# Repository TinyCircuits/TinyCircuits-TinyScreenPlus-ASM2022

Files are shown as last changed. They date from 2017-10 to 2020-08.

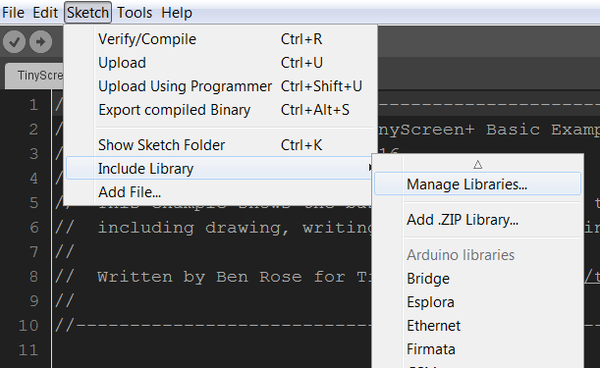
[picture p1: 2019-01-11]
images/tutorial_images/ASM2022-Tutorial-Image-07.png

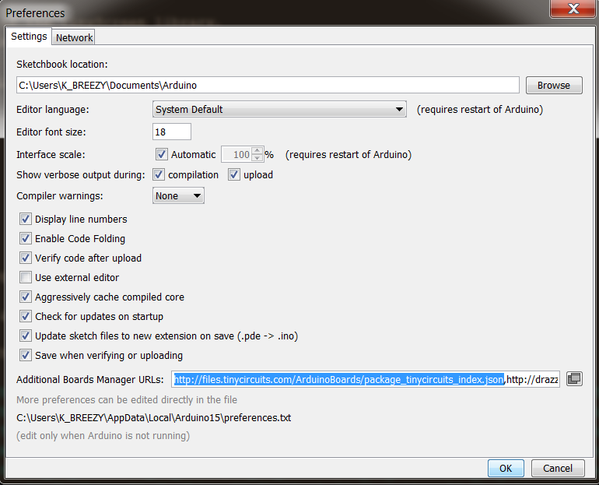
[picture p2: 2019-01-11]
images/tutorial_images/ASM2022-Tutorial-Image-03.png

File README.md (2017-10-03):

# TinyCircuits TinyScreen+ Processor Board
# ASM2022 Rev4

These are the design files for the TinyCircuits ASM2022 Rev 4 PCB.  This is a Tiny processor board that use an Ateml SAMD21 microcontroller and OLED has stackable TinyShield support.  

Format is in Cadsoft Eagle format - Eagle version 6.2 was used for the original design.

#License:

Design by TinyCircuits.
All design files are released under the Creative Commons Attribution Share-Alike 3.0 License, see the following link for details: http://creativecommons.org/licenses/by-sa/3.0

All text above must be included in any redistribution or derived design

This project uses designs and concepts developed as part of the Arduino project and the LilyPad project.  The TinyCircuits design files themselves (schematics, PCB and libraries) are not directly derived from these works' design files and have been created new, however the concepts and basic architecture behind the TinyDuino and TinyLily products are derived and we thank the hard work of the organizations below for their contributions to open-source hardware:
  
Original Arduino Uno Design by Team Arduino

LilyPad Arduino Design by Leah Buechley and Sparkfun Electronics

Please support the open-source hardware community

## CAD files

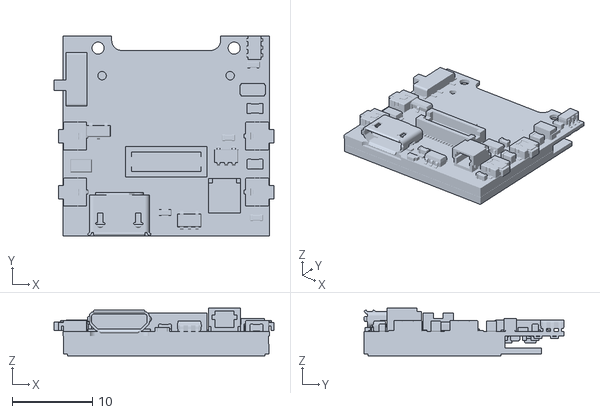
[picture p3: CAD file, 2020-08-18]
cad/TinyScreenPlus_ASM2022_REV4-STL.stl
27.5 x 25.0 x 5.94

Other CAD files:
cad/TinyScreenPlus_ASM2022_REV4-DETAILED_DRAWING-DXF.dxf

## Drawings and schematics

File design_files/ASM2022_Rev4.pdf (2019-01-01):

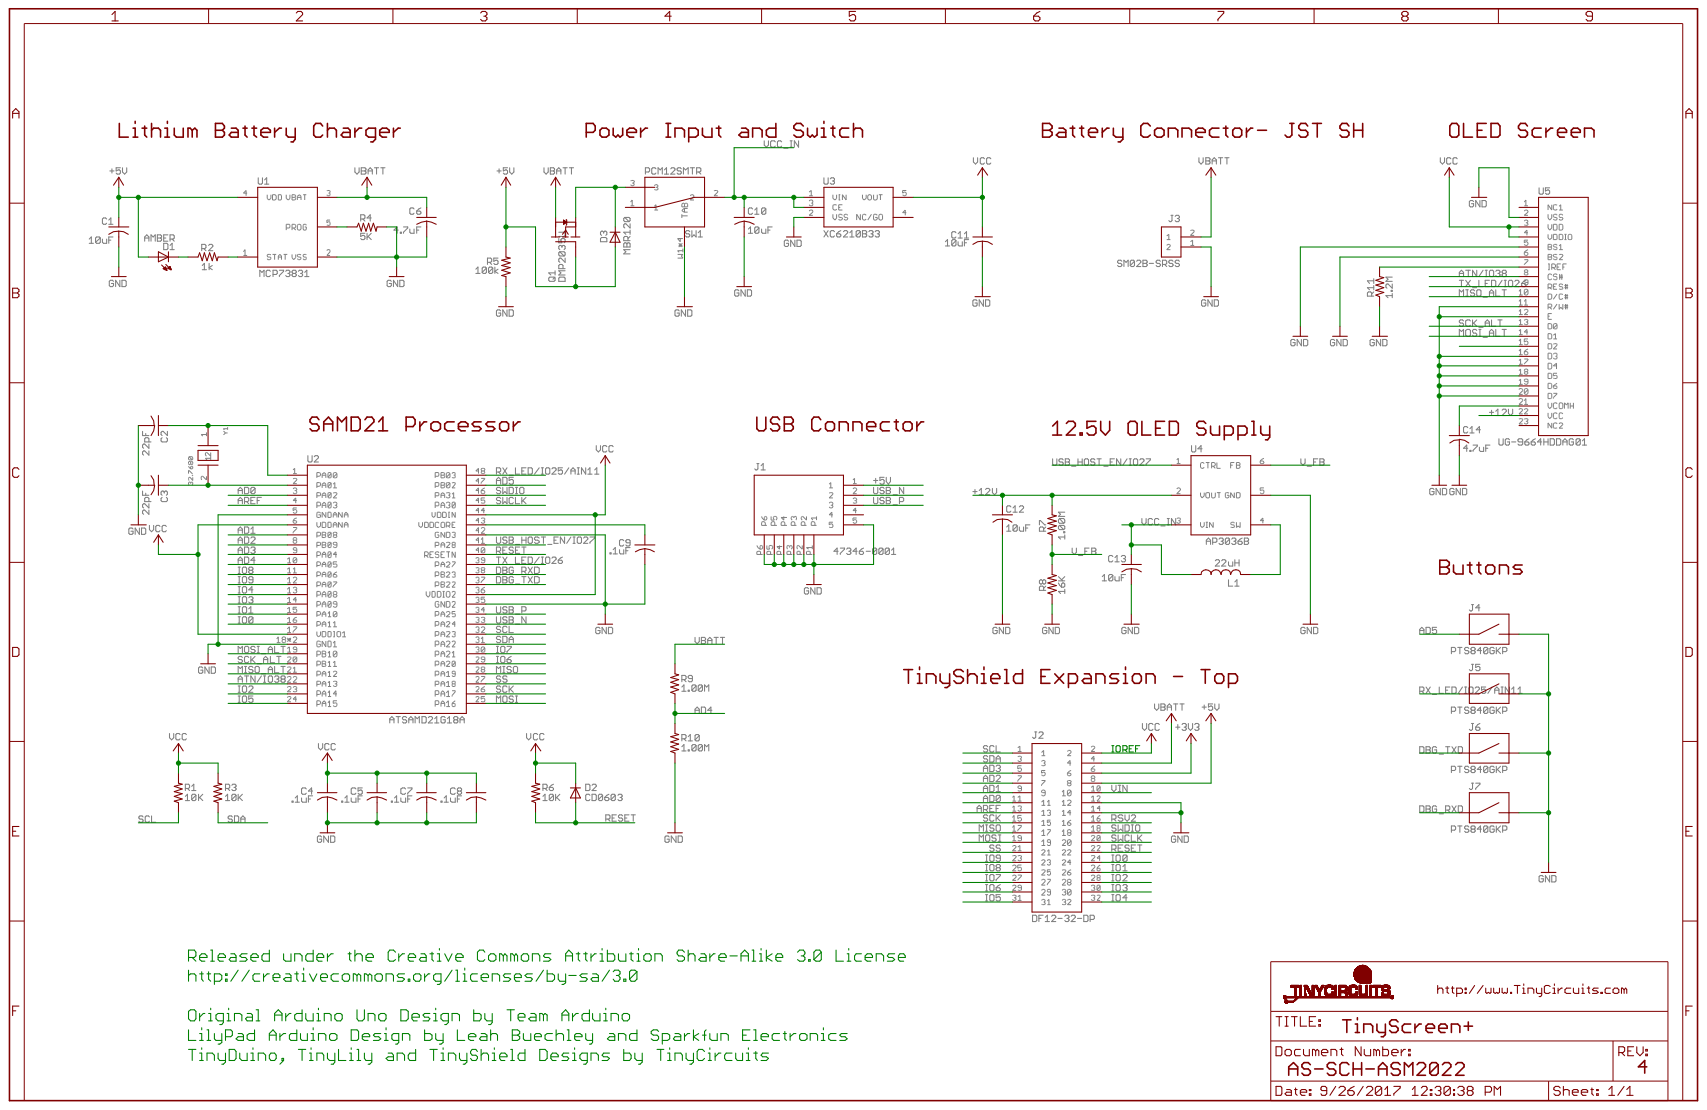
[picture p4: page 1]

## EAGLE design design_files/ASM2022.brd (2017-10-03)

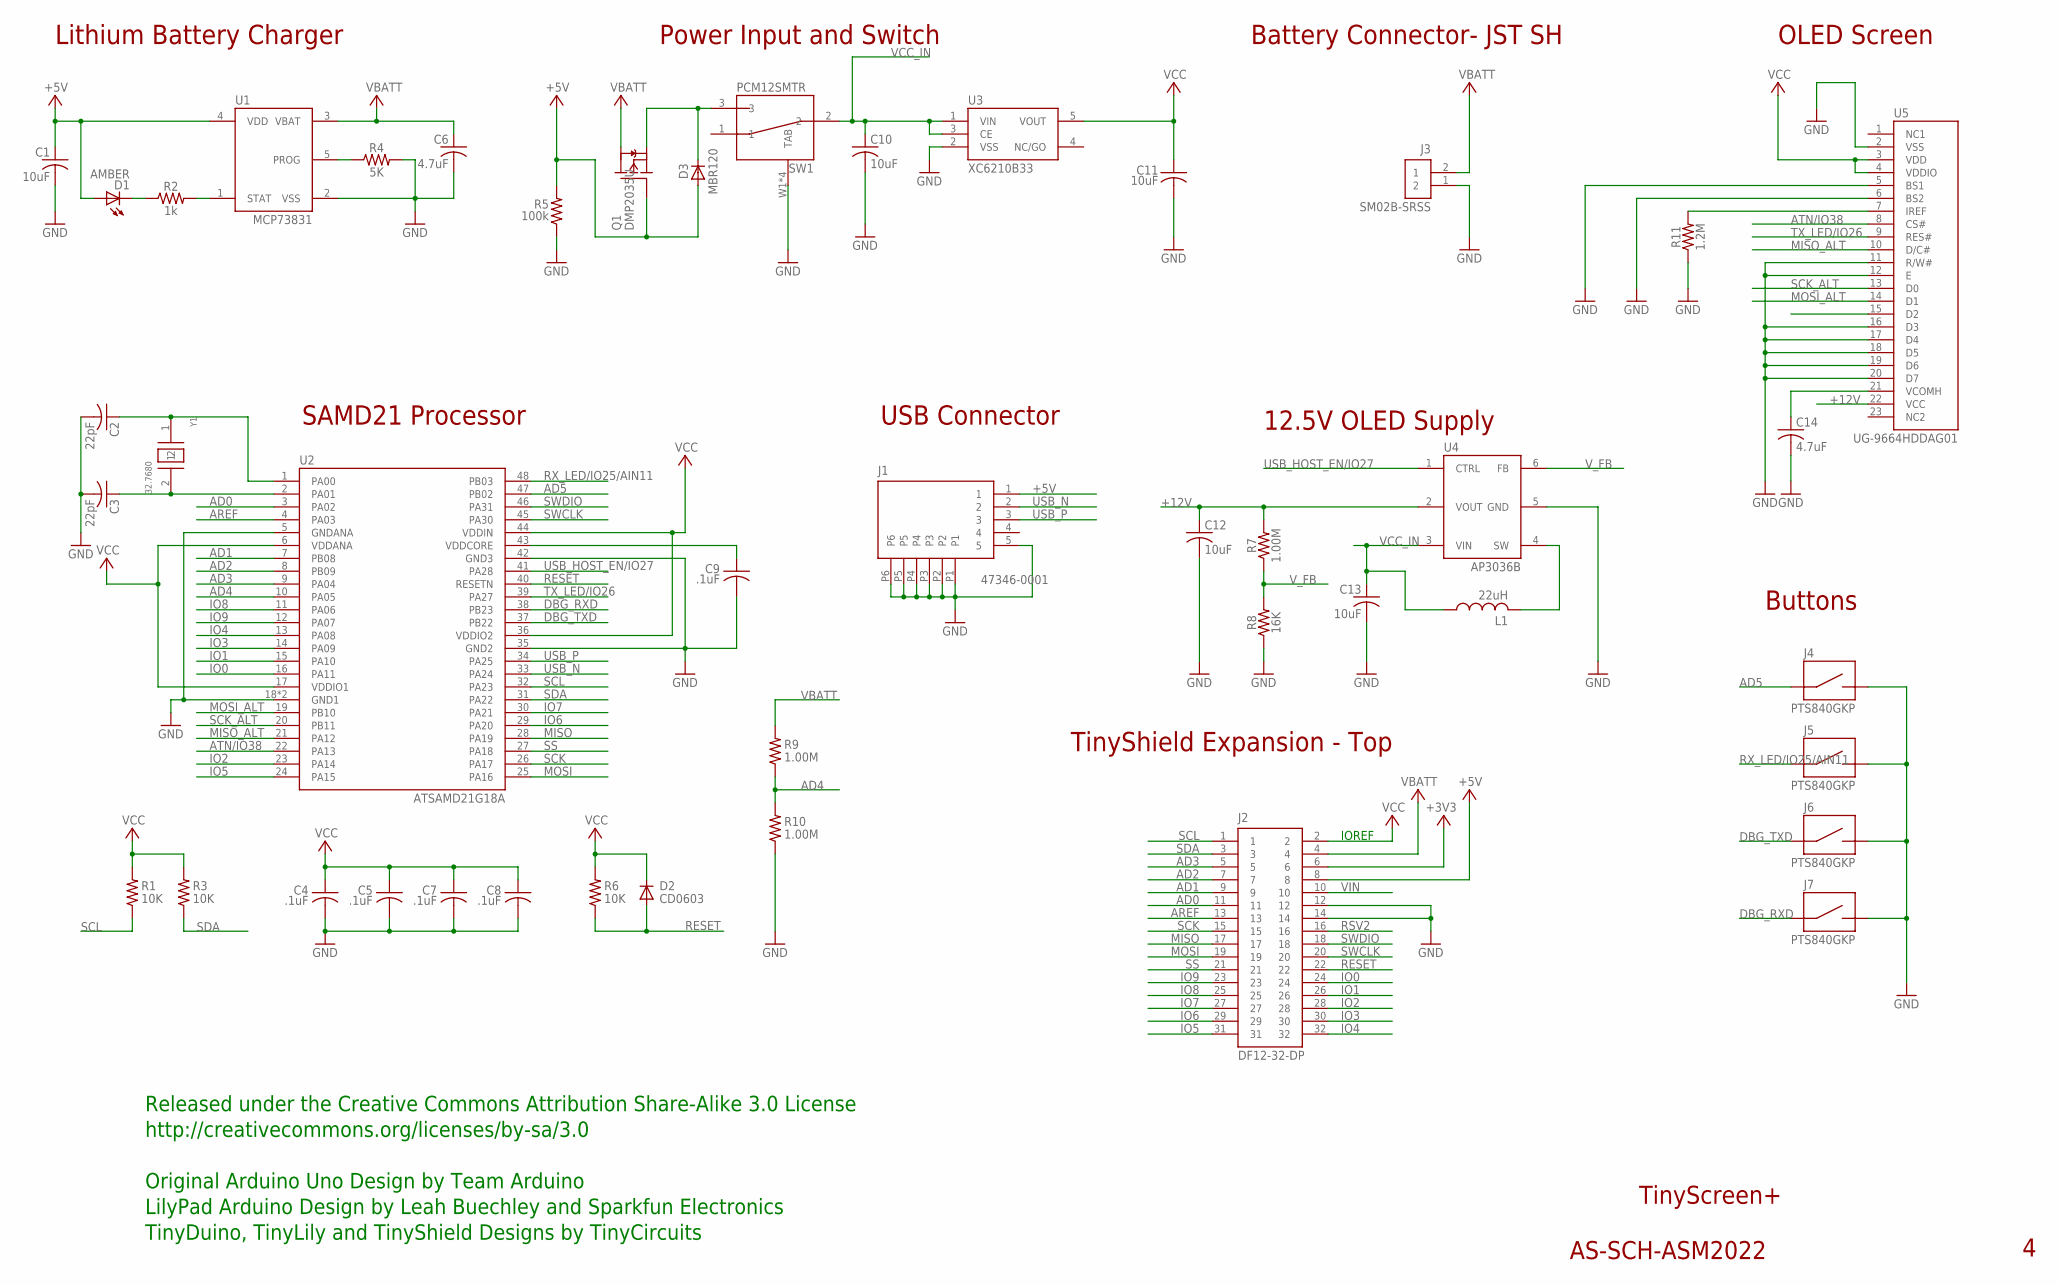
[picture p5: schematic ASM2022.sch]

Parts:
C1, C11, C13: 10uF; C0603; PARTNO AS-ITM-00002
C2, C3: 22pF; C0402; PARTNO AS-ITM-00211
C4, C5, C7, C8, C9: .1uF; C0402; PARTNO AS-ITM-00008
C6: 4.7uF; C0603; PARTNO AS-ITM-00088
C10, C12: 10uF; C0805; PARTNO AS-ITM-00045
C14: 4.7uF; 1206_CAP_TANT; PARTNO AS-ITM-00232
D1: AMBER; LNJ_LED; PARTNO AS-ITM-00026
D2: CD0603; 0603; PARTNO AS-ITM-00009
D3: MBR120; SOD-123FL
J1: 47346-0001; MICRO_USB
J2: DF12-32-DP; PARTNO AS-ITM-00015
J3: SM02B-SRSS; JST_SH_2X1
J4, J5, J6, J7: PTS840GKP; PARTNO AS-ITM-00236
L1: 22uH; R0805
Q1: DMP2035U; SOT23
R1, R3, R6: 10K; 0402; PARTNO AS-ITM-00032
R2: 1k; 0402; PARTNO AS-ITM-00003
R4: 5K; 0402
R5: 100k; 0402; PARTNO AS-ITM-00004
R7, R9, R10: 1.00M; 0402; PARTNO AS-ITM-00005
R8: 16K; 0402; PARTNO AS-ITM-00314
R11: 1.2M; 0402; PARTNO AS-ITM-00280
SW1: PCM12SMTR
U1: MCP73831; SOT-23
U2: ATSAMD21G18A; QFN48; PARTNO AS-ITM-00273
U3: XC6210B33; SOT-25
U4: AP3036B; SOT-23-6; PARTNO AS-ITM-00377
U5: UG-9664HDDAG01; OLED_DISPLAY
Y1: 32.7680; ABS06; PARTNO AS-ITM-00279

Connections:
+3V3: J2.6
+5V: C1.1, D1.A, D3.A, J1.1, J2.8, Q1.B (G), R5.2, U1.4 (VDD)
+12V: C12.1, R7.2, U4.2 (VOUT), U5.22 (VCC)
AD0: J2.11, U2.3 (PA02)
AD1: J2.9, U2.7 (PB08)
AD2: J2.7, U2.8 (PB09)
AD3: J2.5, U2.9 (PA04)
AD4: R9.1, R10.2, U2.10 (PA05)
AD5: J4.1, J4.2 (1), U2.47 (PB02)
AREF: J2.13, U2.4 (PA03)
ATN/IO38: U2.22 (PA13), U5.8 (CS#)
DBG_RXD: J7.1, J7.2 (1), U2.38 (PB23)
DBG_TXD: J6.1, J6.2 (1), U2.37 (PB22)
GND: C1.2, C2.2, C3.2, C4.2, C5.2, C6.2, C7.2, C8.2, C9.2, C10.2, C11.2, C12.2, C13.2, C14.2, J1.5, J1.P1, J1.P2, J1.P3, J1.P4, J1.P5, J1.P6, J2.12, J2.14, J3.1 (2), J4.3 (2), J4.4 (2), J5.3 (2), J5.4 (2), J6.3 (2), J6.4 (2), J7.3 (2), J7.4 (2), R4.2, R5.1, R8.1, R10.1, R11.1, SW1.W1 (TAB), SW1.W2 (TAB), SW1.W3 (TAB), SW1.W4 (TAB), U1.2 (VSS), U2.5 (GNDANA), U2.18 (GND1), U2.35 (GND2), U2.42 (GND3), U2.EXP (GND1), U3.2 (VSS), U4.5 (GND), U5.2 (VSS), U5.5 (BS1), U5.6 (BS2), U5.11 (R/W#), U5.12 (E), U5.16 (D3), U5.17 (D4), U5.18 (D5), U5.19 (D6), U5.20 (D7)
IO0: J2.24, U2.16 (PA11)
IO1: J2.26, U2.15 (PA10)
IO2: J2.28, U2.23 (PA14)
IO3: J2.30, U2.14 (PA09)
IO4: J2.32, U2.13 (PA08)
IO5: J2.31, U2.24 (PA15)
IO6: J2.29, U2.29 (PA20)
IO7: J2.27, U2.30 (PA21)
IO8: J2.25, U2.11 (PA06)
IO9: J2.23, U2.12 (PA07)
MISO: J2.17, U2.28 (PA19)
MISO_ALT: U2.21 (PA12), U5.10 (D/C#)
MOSI: J2.19, U2.25 (PA16)
MOSI_ALT: U2.19 (PB10), U5.14 (D1)
unnamed: C2.1, U2.1 (PA00), Y1.1
unnamed: D3.C, Q1.E (S), SW1.3
unnamed: C3.1, U2.2 (PA01), Y1.2
unnamed: L1.2, U4.4 (SW)
unnamed: D1.C, R2.1
unnamed: R4.1, U1.5 (PROG)
unnamed: R2.2, U1.1 (STAT)
unnamed: C9.1, U2.43 (VDDCORE)
unnamed: R11.2, U5.7 (IREF)
unnamed: C14.1, U5.21 (VCOMH)
RESET: D2.A, J2.22, R6.1, U2.40 (RESETN)
RSV2: J2.16
RX_LED/IO25/AIN11: J5.1, J5.2 (1), U2.48 (PB03)
SCK: J2.15, U2.26 (PA17)
SCK_ALT: U2.20 (PB11), U5.13 (D0)
SCL: J2.1, R1.1, U2.32 (PA23)
SDA: J2.3, R3.1, U2.31 (PA22)
SS: J2.21, U2.27 (PA18)
SWCLK: J2.20, U2.45 (PA30)
SWDIO: J2.18, U2.46 (PA31)
TX_LED/IO26: U2.39 (PA27), U5.9 (RES#)
USB_HOST_EN/IO27: U2.41 (PA28), U4.1 (CTRL)
USB_N: J1.2, U2.33 (PA24)
USB_P: J1.3, U2.34 (PA25)
VBATT: C6.1, J2.4, J3.2 (1), Q1.C (D), R9.2, U1.3 (VBAT)
VCC: C4.1, C5.1, C7.1, C8.1, C11.1, D2.C, J2.2, R1.2, R3.2, R6.2, U2.6 (VDDANA), U2.17 (VDDIO1), U2.36 (VDDIO2), U2.44 (VDDIN), U3.5 (VOUT), U5.3 (VDD), U5.4 (VDDIO)
VCC_IN: C10.1, C13.1, L1.1, SW1.2, U3.1 (VIN), U3.3 (CE), U4.3 (VIN)
VIN: J2.10
V_FB: R7.1, R8.2, U4.6 (FB)

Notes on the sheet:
IOREF
TinyShield Expansion - Top
SAMD21 Processor
Power Input and Switch
TinyScreen+
AS-SCH-ASM2022
Released under the Creative Commons Attribution Share-Alike 3.0 License
http://creativecommons.org/licenses/by-sa/3.0
Original Arduino Uno Design by Team Arduino
TinyDuino, TinyLily and TinyShield Designs by TinyCircuits
LilyPad Arduino Design by Leah Buechley and Sparkfun Electronics
Lithium Battery Charger
Battery Connector- JST SH
OLED Screen
12.5V OLED Supply
Buttons
USB Connector

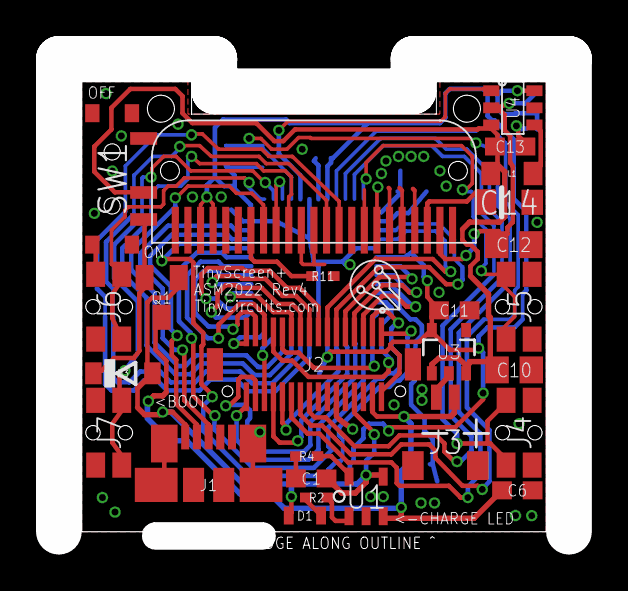
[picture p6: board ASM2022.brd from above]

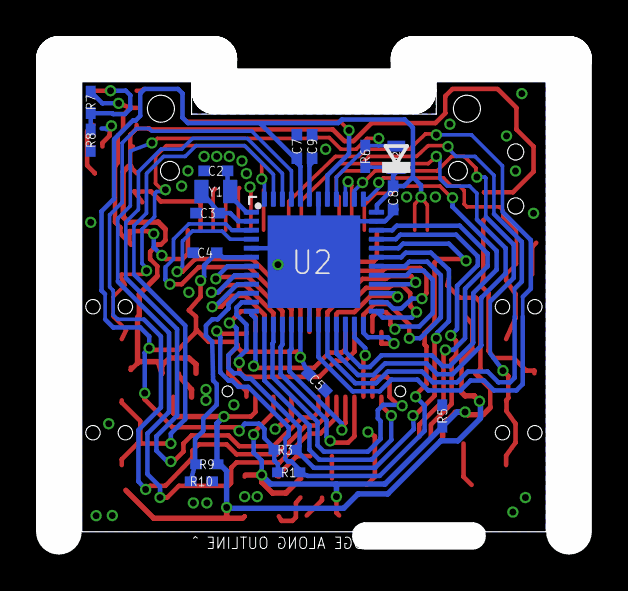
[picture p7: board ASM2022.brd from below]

Board: 2 copper layers, 28.3 x 26.5 mm, 45 parts (18 on the bottom side), 54 nets.

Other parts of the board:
U$1: DOCFIELD-TINYCIRCUITS-PCB

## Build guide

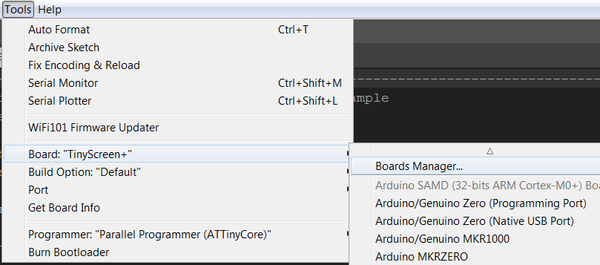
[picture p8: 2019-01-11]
images/tutorial_images/ASM2022-Tutorial-Image-04.png

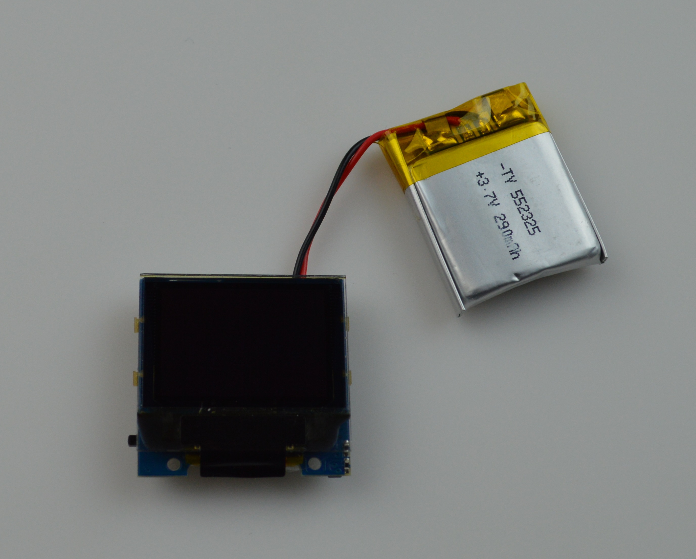
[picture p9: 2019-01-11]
images/tutorial_images/ASM2022-Tutorial-Image-01.jpg

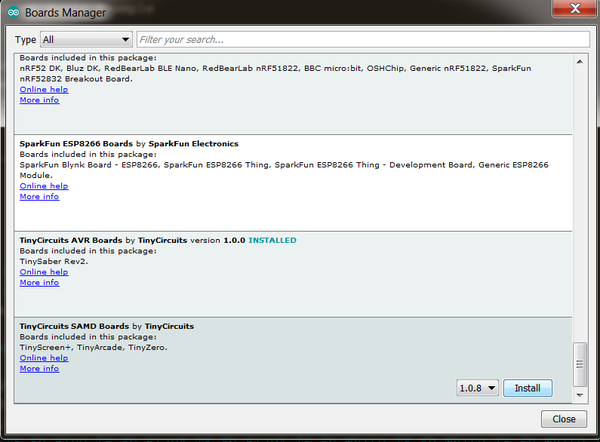
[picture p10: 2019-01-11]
images/tutorial_images/ASM2022-Tutorial-Image-06.png

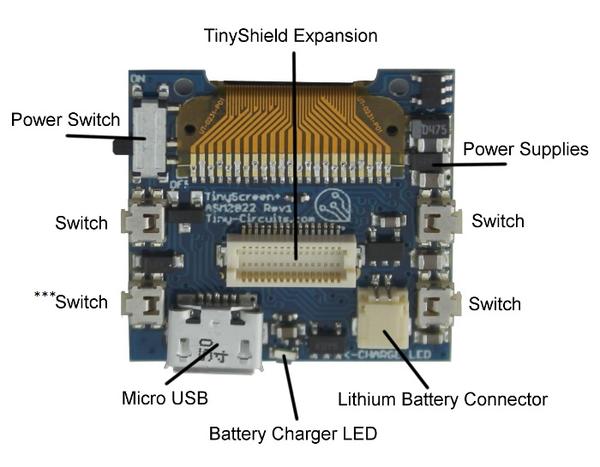
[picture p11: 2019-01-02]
images/tutorial_images/ASM2022-Tutorial-Image-13_Temporary.png

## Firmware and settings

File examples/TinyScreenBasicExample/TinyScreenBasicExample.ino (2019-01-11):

/*
  TinyScreen/TinyScreen+ Basic Example

  This example shows the basic functionality of the TinyScreen library,
  including drawing, writing bitmaps, and printing text.

  Written 26 January 2016
  By Ben Rose
  Modified 07 January 2019
  By Hunter Hykes

  https://TinyCircuits.com
*/

#include <Wire.h>
#include <SPI.h>
#include <TinyScreen.h>

//Library must be passed the board type
//TinyScreenDefault for TinyScreen shields
//TinyScreenAlternate for alternate address TinyScreen shields
//TinyScreenPlus for TinyScreen+
TinyScreen display = TinyScreen(TinyScreenPlus);

//This is an example 17x12 pixel bitmap using TS library color definitions
unsigned char flappyBirdBitmap[204]={
  TS_8b_Blue,TS_8b_Blue,TS_8b_Blue,TS_8b_Blue,TS_8b_Blue,TS_8b_Blue,TS_8b_Black,TS_8b_Black,TS_8b_Black,TS_8b_Black,TS_8b_Black,TS_8b_Black,TS_8b_Blue,TS_8b_Blue,TS_8b_Blue,TS_8b_Blue,TS_8b_Blue,
  TS_8b_Blue,TS_8b_Blue,TS_8b_Blue,TS_8b_Blue,TS_8b_Black,TS_8b_Black,TS_8b_White,TS_8b_White,TS_8b_White,TS_8b_Black,TS_8b_White,TS_8b_White,TS_8b_Black,TS_8b_Blue,TS_8b_Blue,TS_8b_Blue,TS_8b_Blue,
  TS_8b_Blue,TS_8b_Blue,TS_8b_Blue,TS_8b_Black,TS_8b_White,TS_8b_White,TS_8b_Yellow,TS_8b_Yellow,TS_8b_Black,TS_8b_White,TS_8b_White,TS_8b_White,TS_8b_White,TS_8b_Black,TS_8b_Blue,TS_8b_Blue,TS_8b_Blue,
  TS_8b_Blue,TS_8b_Black,TS_8b_Black,TS_8b_Black,TS_8b_Black,TS_8b_Yellow,TS_8b_Yellow,TS_8b_Yellow,TS_8b_Black,TS_8b_White,TS_8b_White,TS_8b_White,TS_8b_Black,TS_8b_White,TS_8b_Black,TS_8b_Blue,TS_8b_Blue,
  TS_8b_Black,TS_8b_White,TS_8b_White,TS_8b_White,TS_8b_White,TS_8b_Black,TS_8b_Yellow,TS_8b_Yellow,TS_8b_Black,TS_8b_White,TS_8b_White,TS_8b_White,TS_8b_Black,TS_8b_White,TS_8b_Black,TS_8b_Blue,TS_8b_Blue,
  TS_8b_Black,TS_8b_White,TS_8b_White,TS_8b_White,TS_8b_White,TS_8b_White,TS_8b_Black,TS_8b_Yellow,TS_8b_Yellow,TS_8b_Black,TS_8b_White,TS_8b_White,TS_8b_White,TS_8b_White,TS_8b_Black,TS_8b_Blue,TS_8b_Blue,
  TS_8b_Black,TS_8b_Yellow,TS_8b_White,TS_8b_White,TS_8b_White,TS_8b_Yellow,TS_8b_Black,TS_8b_Yellow,TS_8b_Yellow,TS_8b_Yellow,TS_8b_Black,TS_8b_Black,TS_8b_Black,TS_8b_Black,TS_8b_Black,TS_8b_Black,TS_8b_Blue,
  TS_8b_Blue,TS_8b_Black,TS_8b_Yellow,TS_8b_Yellow,TS_8b_Yellow,TS_8b_Black,TS_8b_Yellow,TS_8b_Yellow,TS_8b_Yellow,TS_8b_Black,TS_8b_Red,TS_8b_Red,TS_8b_Red,TS_8b_Red,TS_8b_Red,TS_8b_Red,TS_8b_Black,
  TS_8b_Blue,TS_8b_Blue,TS_8b_Black,TS_8b_Black,TS_8b_Black,TS_8b_Yellow,TS_8b_Yellow,TS_8b_Yellow,TS_8b_Yellow,TS_8b_Black,TS_8b_Red,TS_8b_Black,TS_8b_Black,TS_8b_Black,TS_8b_Black,TS_8b_Black,TS_8b_Black,
  TS_8b_Blue,TS_8b_Blue,TS_8b_Black,TS_8b_Yellow,TS_8b_Yellow,TS_8b_Yellow,TS_8b_Yellow,TS_8b_Yellow,TS_8b_Yellow,TS_8b_Black,TS_8b_Red,TS_8b_Red,TS_8b_Red,TS_8b_Red,TS_8b_Red,TS_8b_Black,TS_8b_Blue,
  TS_8b_Blue,TS_8b_Blue,TS_8b_Blue,TS_8b_Black,TS_8b_Black,TS_8b_Yellow,TS_8b_Yellow,TS_8b_Yellow,TS_8b_Yellow,TS_8b_Yellow,TS_8b_Black,TS_8b_Black,TS_8b_Black,TS_8b_Black,TS_8b_Black,TS_8b_Blue,TS_8b_Blue,
  TS_8b_Blue,TS_8b_Blue,TS_8b_Blue,TS_8b_Blue,TS_8b_Blue,TS_8b_Black,TS_8b_Black,TS_8b_Black,TS_8b_Black,TS_8b_Black,TS_8b_Blue,TS_8b_Blue,TS_8b_Blue,TS_8b_Blue,TS_8b_Blue,TS_8b_Blue,TS_8b_Blue
};

void setup(void) {
  Wire.begin();//initialize I2C before we can initialize TinyScreen- not needed for TinyScreen+
  display.begin();
  //setBrightness(brightness);//sets main current level, valid levels are 0-15
  display.setBrightness(10);
}

void loop() {
  hardwareDrawCommands();
  drawPixels();
  drawBitmap();
  //setFlip(boolean);//done in hardware on the SSD1331
  display.setFlip(true);
  delay(1000);
  display.setFlip(false);
  delay(1000);
  writeText();
  delay(1000);
  readInput();
}

void hardwareDrawCommands(){
  //Accelerated drawing commands are executed by the display controller
  //clearScreen();//clears entire display- the same as clearWindow(0,0,96,64)
  display.clearScreen();
  //drawRect(x stary, y start, width, height, fill, 8bitcolor);//sets specified OLED controller memory to an 8 bit color, fill is a boolean- TSRectangleFilled or TSRectangleNoFill
  display.drawRect(10,10,76,44,TSRectangleFilled,TS_8b_Red);
  //drawRect(x stary, y start, width, height, fill, red, green, blue);//like above, but uses 6 bit color values. Red and blue ignore the LSB.
  display.drawRect(15,15,66,34,TSRectangleFilled,20,30,60);
  //clearWindow(x start, y start, width, height);//clears specified OLED controller memory
  display.clearWindow(20,20,56,24);
  //drawLine(x1, y1, x2, y2, 8bitcolor);//draw a line from (x1,y1) to (x2,y2) with an 8 bit color
  display.drawLine(0,0,95,63,TS_8b_Green);
  //drawLine(x1, y1, x2, y2, red, green, blue);//like above, but uses 6 bit color values. Red and blue ignore the LSB.
  display.drawLine(0,63,95,0,0,63,0);
  delay(1000);
  //use 16 bit version of drawLine to fade a rectangle from blue to green:
  for(int i=0;i<64;i++){
    display.drawLine(0,i,95,i,0,i,63-i);
  }
  delay(1000);
}

void drawPixels(){
  //writing pixels one by one is slow, but neccessary for drawing shapes other than lines and rectangles
  //we'll implement a simple circle drawing algorithm from http://en.wikipedia.org/wiki/Midpoint_circle_algorithm
  drawCircle(40,30,30,TS_8b_Red);
  drawCircle(45,30,25,TS_8b_Yellow);
  drawCircle(50,30,20,TS_8b_Blue);
  drawCircle(55,30,15,TS_8b_Brown);
  drawCircle(60,30,10,TS_8b_Green);
  drawCircle(65,30,5,TS_8b_Black);
  delay(1000);
}

void drawCircle(int x0, int y0, int radius, uint8_t color)
{
  int x = radius;
  int y = 0;
  int radiusError = 1-x;
 
  while(x >= y)
  {
    //drawPixel(x,y,color);//set pixel (x,y) to specified color. This is slow because we need to send commands setting the x and y, then send the pixel data.
    display.drawPixel(x + x0, y + y0, color);
    display.drawPixel(y + x0, x + y0, color);
    display.drawPixel(-x + x0, y + y0, color);
    display.drawPixel(-y + x0, x + y0, color);
    display.drawPixel(-x + x0, -y + y0, color);
    display.drawPixel(-y + x0, -x + y0, color);
    display.drawPixel(x + x0, -y + y0, color);
    display.drawPixel(y + x0, -x + y0, color);
    y++;
    if (radiusError<0)
    {
      radiusError += 2 * y + 1;
    }
    else
    {
      x--;
      radiusError += 2 * (y - x) + 1;
    }
  }
}

void drawBitmap(){
  //set a background that matches
  display.drawRect(0,0,96,64,TSRectangleFilled,TS_8b_Blue);
  //let's set up for a bitmap at (40,30) that is 17 pixels wide and 12 pixels tall:
  //setX(x start, x end);//set OLED RAM to x start, wrap around at x end
  display.setX(40,40+17-1);
  //setY(y start, y end);//set OLED RAM to y start, wrap around at y end
  display.setY(30,30+12-1);
  //now start a data transfer
  display.startData();
  //writeBuffer(buffer,count);//optimized write of a large buffer of 8 bit data.
  display.writeBuffer(flappyBirdBitmap,17*12);
  display.endTransfer();
  delay(1000);
  
}

void writeText(){
  display.clearScreen();
  //setFont sets a font info header from font.h
  //information for generating new fonts is included in font.h
  display.setFont(thinPixel7_10ptFontInfo);
  //getPrintWidth(character array);//get the pixel print width of a string
  int width=display.getPrintWidth("Example Text!");
  //setCursor(x,y);//set text cursor position to (x,y)- in this example, the example string is centered
  display.setCursor(48-(width/2),10);
  //fontColor(text color, background color);//sets text and background color
  display.fontColor(TS_8b_Green,TS_8b_Black);
  display.print("Example Text!");
  display.setCursor(15,25);
  display.fontColor(TS_8b_Blue,TS_8b_Black);
  display.print("More example Text!");
  display.setCursor(3,40);
  display.fontColor(TS_8b_Red,TS_8b_Black);
  display.print("(Does not wrap)");
  delay(1000);
}

void readInput() {
  display.fontColor(TS_8b_White,TS_8b_Black);
  display.clearScreen();
  display.setCursor(48 - (display.getPrintWidth("Press a Button!") / 2), 32 - (display.getFontHeight() / 2));
  display.print("Press a Button!");
  unsigned long startTime = millis();
  while (millis() - startTime < 3000)buttonLoop();
  display.clearScreen();
  display.setFlip(true);
  display.setCursor(48 - (display.getPrintWidth("Press a Button!") / 2), 32 - (display.getFontHeight() / 2));
  display.print("Press a Button!");
  startTime = millis();
  while (millis() - startTime < 3000)buttonLoop();
  display.clearScreen();
  display.setFlip(false);
}

void buttonLoop() {
  display.setCursor(0, 0);
  //getButtons() function can be used to test if any button is pressed, or used like:
  //getButtons(TSButtonUpperLeft) to test a particular button, or even like:
  //getButtons(TSButtonUpperLeft|TSButtonUpperRight) to test multiple buttons
  //results are flipped as you would expect when setFlip(true)
  if (display.getButtons(TSButtonUpperLeft)) {
    display.println("Pressed!");
  } else {
    display.println("          ");
  }
  display.setCursor(0, 54);
  if (display.getButtons(TSButtonLowerLeft)) {
    display.println("Pressed!");
  } else {
    display.println("          ");
  }
  display.setCursor(95 - display.getPrintWidth("Pressed!"), 0);
  if (display.getButtons(TSButtonUpperRight)) {
    display.println("Pressed!");
  } else {
    display.println("          ");
  }
  display.setCursor(95 - display.getPrintWidth("Pressed!"), 54);
  if (display.getButtons(TSButtonLowerRight)) {
    display.println("Pressed!");
  } else {
    display.println("          ");
  }
}

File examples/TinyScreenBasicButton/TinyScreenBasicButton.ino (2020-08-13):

//-------------------------------------------------------------------------------
//  TinyCircuits TinyScreen/TinyScreen+ Basic Button Interaction Example
//  
//  This example shows the basic functionality of the TinyScreen/TinyScreen+
//  buttons and how to interact with them.
//
//  Written by Laveréna Wienclaw August 13 2020
//-------------------------------------------------------------------------------

#include <Wire.h>
#include <SPI.h>
#include <TinyScreen.h>

/* Library must be initialized with the board type
 * TinyScreenDefault for TinyScreen shields
 * TinyScreenAlternate for alternate address TinyScreen shields
 * TinyScreenPlus for TinyScreen+    */
TinyScreen display = TinyScreen(TinyScreenPlus);

// Make Serial Monitor compatible for all TinyCircuits processors
#if defined(ARDUINO_ARCH_AVR)
  #define SerialMonitorInterface Serial
#elif defined(ARDUINO_ARCH_SAMD)
  #define SerialMonitorInterface SerialUSB
#endif


void setup(void) {
  Wire.begin(); //initialize I2C before we can initialize TinyScreen, not needed for TinyScreen+
  SerialMonitorInterface.begin(9600);
  display.begin();
  display.setBrightness(10); //sets main current level, valid levels are 0-15
  display.clearScreen();
  display.setFont(thinPixel7_10ptFontInfo);
}

void loop() {
  buttonLoop();
  delay(100); // make screen look more stable between text printing and clearing
  display.clearScreen();
}

/*
  - getButtons() function can be used to test if any button is pressed
  - getButtons(TSButtonUpperLeft) to test a particular button
  - getButtons(TSButtonUpperLeft|TSButtonUpperRight) to test multiple buttons
  - Results are flipped as you would expect when setFlip(true) is used
*/
void buttonLoop() {
  display.setCursor(0, 0);

  if (display.getButtons(TSButtonUpperLeft)) {
    SerialMonitorInterface.println("upper left pressed");
    display.println("Pressed!");
  } 
  
  display.setCursor(0, 54);
  if (display.getButtons(TSButtonLowerLeft)) {
    SerialMonitorInterface.println("lower left pressed");
    display.println("Pressed!");
  } 
  
  display.setCursor(95 - display.getPrintWidth("Pressed!"), 0);
  if (display.getButtons(TSButtonUpperRight)) {
    SerialMonitorInterface.println("upper right pressed");
    display.println("Pressed!");
  } 
  
  display.setCursor(95 - display.getPrintWidth("Pressed!"), 54);
  if (display.getButtons(TSButtonLowerRight)) {
    SerialMonitorInterface.println("lower right pressed");
    display.println("Pressed!");
  } 
}

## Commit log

2017-10-03 Update to Rev 4 PCB
    [ASM2022.brd, ASM2022.sch]
2019-01-01 update design format
    [ASM2022.brd, ASM2022.sch]
2020-06-26 Add CAD data
2020-06-30 Rename files, add dxf, and use new 2D drawing template
    [TinyScreenPlus_ASM2022_DRAWING_REV4.dxf]
2020-07-01 Remove vias in models & drawings, add compact dimension images, and remove file to reduce size
    [TinyScreenPlus_ASM2022_DRAWING_REV4.dxf, TinyScreenPlus_DXF_ASM2022_REV4.dxf]
2020-07-02 Add zip of all CAD files
2020-08-13 new button example
2020-08-18 Update CAD drawings
    [TinyScreenPlus_ASM2022_REV4-DETAILED_DRAWING-DXF.dxf, TinyScreenPlus_ASM2022_REV4-STL.stl, TinyScreenPlus_DXF_ASM2022_REV4.dxf]
